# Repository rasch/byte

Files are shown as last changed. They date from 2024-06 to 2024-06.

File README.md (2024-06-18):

# byte

The byte Keyboard, Version 0.1.0

An 8-key, one-handed, business card sized keyboard.

- Keyboard Maintainer: [rasch](https://github.com/rasch/byte)
- Hardware Supported: Byte 0.1.0 (stm32f072)
- Hardware Availability: [byte]

## Getting Board

Check out [the byte releases page][releases] for the required files to get
PCBs manufactured (`plot.zip`) and/or assembled (`bom.csv` and `cpl.csv`). For
those with soldering abilities, an interactive BOM/CPL HTML file (`ibom.html`)
is provided to aid with self-assembly.

During development, it may be preferable (faster) to run rule checks and test
builds locally. There is a `run` shell script in the root of this repository
that is used by the CI/CD for building releases. This script can be run
directly (`./run pcb`), but it requires the `kicad-cli` 8.0+ release to be
installed. Instead, if `podman` is available, it is recommended to use the
`build` script. This script just runs the `./run` script in the
`kicad/kicad:8.0` container. The build files and reports (ERC/DRC) are placed in
the `dist` directory.

The byte Keyboard, Version 0.1.0

In addition to the parts listed in the BOM, the following will be needed for a
complete keyboard:

- 8 x Kailh Low Profile Choc Switches (PG1350)
- 8 x 1u Choc Keycaps (such as MBK)
- USB-C cable to connect to device
- Some rubber feet or neoprene adhesive rubber pads to prevent the board from
  sliding all over the place

## Firmware Installation

Download the firmware, `byte_left.bin` or `byte_right.bin`, from [the byte
releases page][releases]. To flash the keyboard, press the reset button on the
PCB to enter bootloader mode, then run:

```sh
# left-handed artsey
dfu-util -a 0 -d 0483:DF11 -s 0x8000000:leave -D byte_left.bin

# or right-handed artsey
dfu-util -a 0 -d 0483:DF11 -s 0x8000000:leave -D byte_right.bin
```

For details on compiling the firmware, please see the [Github Actions
workflow][build].

## Keymap

The firmware, `byte_left.bin` and `byte_right.bin`, keymaps are based on the
[ARTSEY v0.9.0][artsey] layout. This layout is of limited use for most people,
but it's fun to learn and very useful for those with certain disabilities. The
firmware keymap configuration, `fw/keymaps/left/keymap.c`, provides a good
starting point for making the byte yours! It can be a macropad for your favorite
game, for drawing with Inkscape, for designing keyboards with KiCad, or even
making PowerPoint presentations (Ew!). Check out the [QMK documentation][qmk] to
get inspiration for your own macropad layout!

## License

[Solderpad Hardware License v2.1](LICENSE)

[byte]: https://github.com/rasch/byte
[releases]: https://github.com/rasch/byte/releases/
[image]: https://i.imgur.com/48yj4tK.jpg
[image-back]: https://i.imgur.com/SwSe1no.jpg
[build]: https://github.com/rasch/byte/blob/main/.github/workflows/fw.yml
[artsey]: https://artsey.io/
[qmk]: https://docs.qmk.fm/#/

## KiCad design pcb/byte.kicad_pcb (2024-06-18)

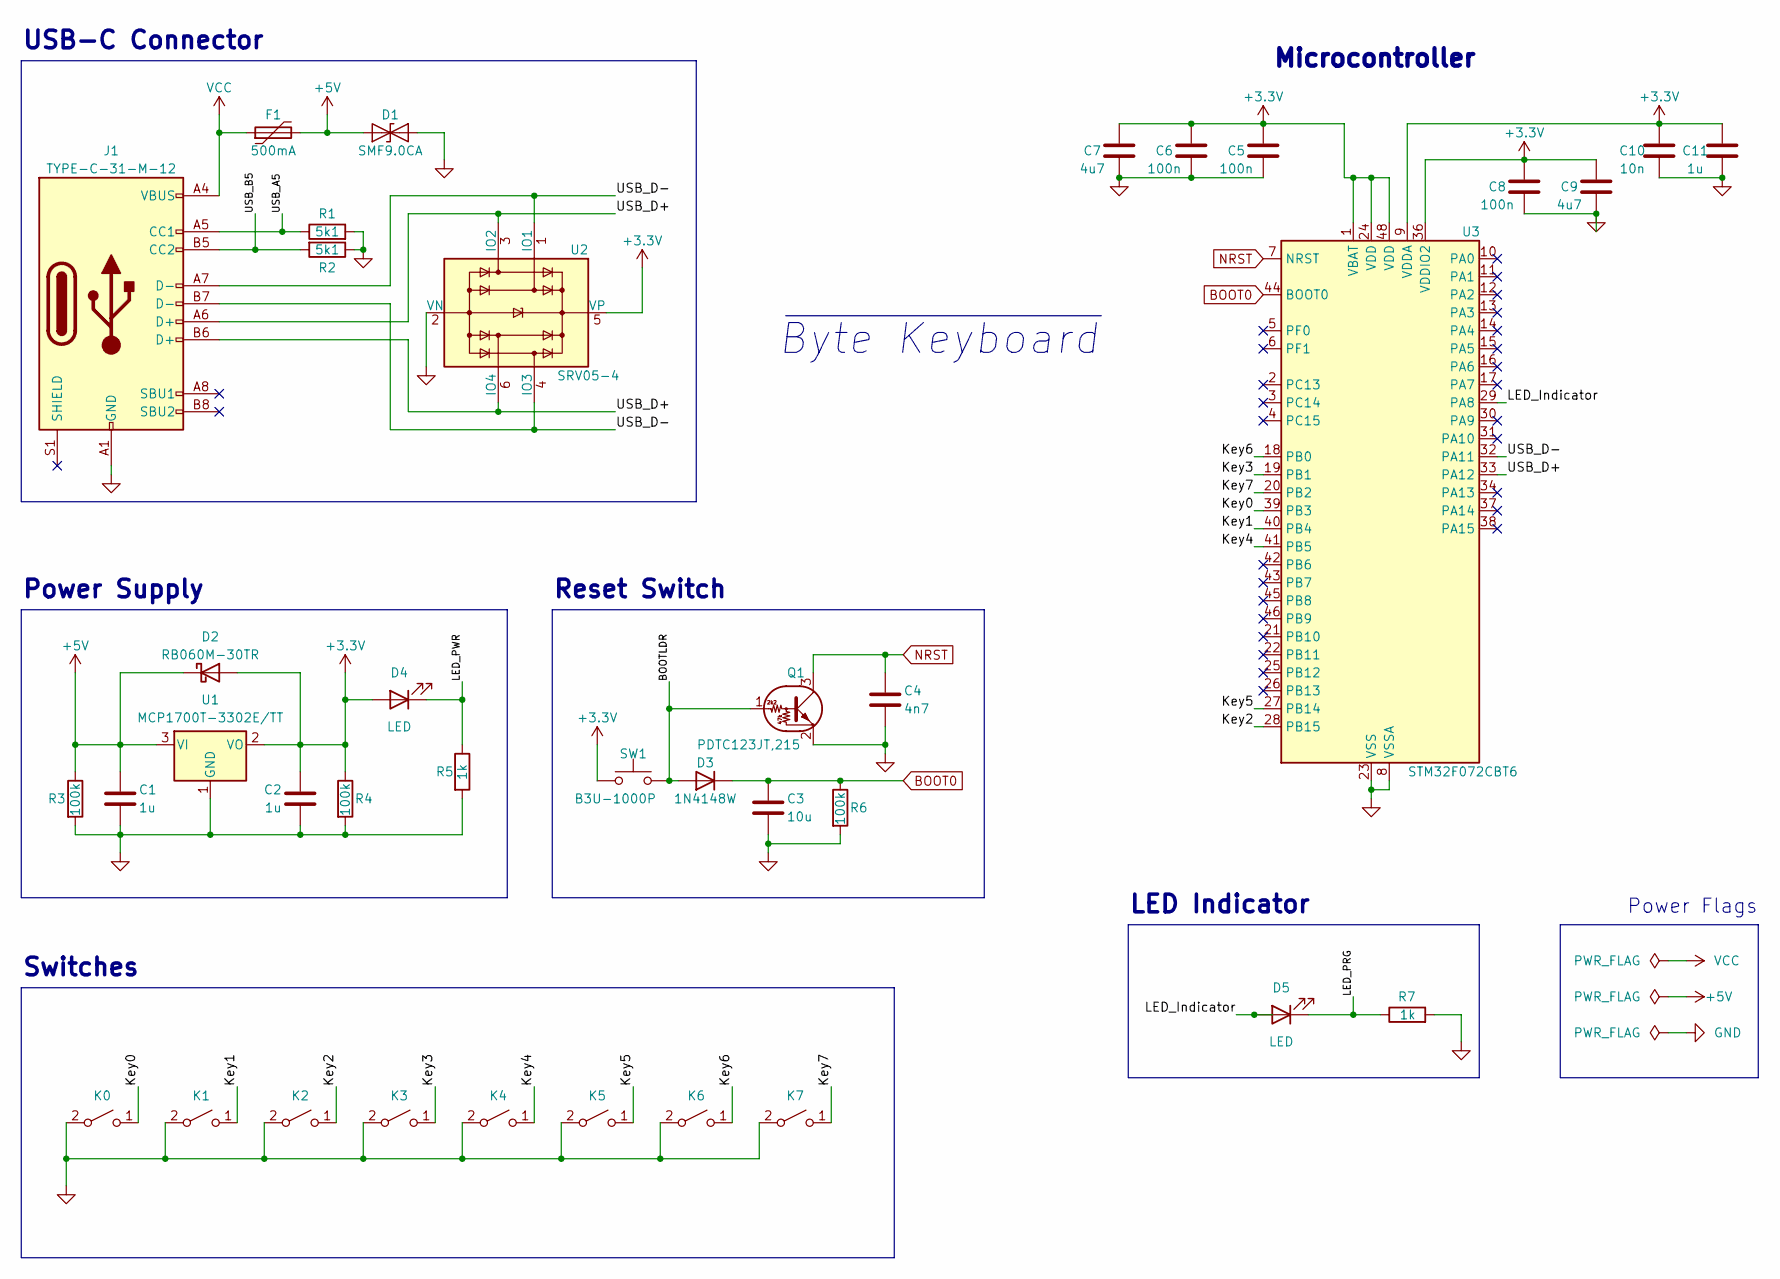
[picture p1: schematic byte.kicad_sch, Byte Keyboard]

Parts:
C1, C2, C11: 1u; C_0805_2012Metric; Part Name Capacitor; LCSC Part C28323
C3: 10u; C_0805_2012Metric; Part Name Capacitor; LCSC Part C17024
C4: 4n7; C_0805_2012Metric; Part Name Capacitor; LCSC Part C717014
C5, C6, C8: 100n; C_0805_2012Metric; Part Name Capacitor; LCSC Part C49678
C7, C9: 4u7; C_0805_2012Metric; Part Name Capacitor; LCSC Part C87998
C10: 10n; C_0805_2012Metric; Part Name Capacitor; LCSC Part C1710
D1: SMF9.0CA; D_SOD-123; Part Name Bidirectional Diode; LCSC Part C435473
D2: RB060M-30TR; D_SOD-123; Part Name Schottky Barrier Diodes; LCSC Part C559324
D3: 1N4148W; D_SOD-123; Part Name Diode; LCSC Part C81598
D4, D5: LED; LED_0603_1608Metric; Part Name Red LED; LCSC Part C84263
F1: 500mA; Fuse_1206_3216Metric; Part Name Polyfuse; LCSC Part C151162
J1: TYPE-C-31-M-12; USB_C_Receptacle_HRO_TYPE-C-31-M-12; Part Name USB C; LCSC Part C165948
K0, K1, K2, K3, K4, K5, K6, K7: SW_KEY; Choc_PG1350_Choc_Spacing
Q1: PDTC123JT,215; SOT-23; Part Name NPN Transistor; LCSC Part C406040
R1, R2: 5k1; R_0805_2012Metric; Part Name Resistor; LCSC Part C27834
R3, R4, R6: 100k; R_0805_2012Metric; Part Name Resistor; LCSC Part C149504
R5, R7: 1k; R_0805_2012Metric; Part Name Resistor; LCSC Part C25318
SW1: B3U-1000P; SW_SPST_B3U-1000P; Part Name Reset Button; LCSC Part C231329
U1: MCP1700T-3302E/TT; SOT-23; Part Name Dropout Regulator; LCSC Part C39051
U2: SRV05-4; SOT-23-6; Part Name TVS Diode Array; LCSC Part C558418
U3: STM32F072CBT6; LQFP-48_7x7mm_P0.5mm; Part Name MCU; LCSC Part C81720

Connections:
+3.3V: C2.1, C5.1, C6.2, C7.1, C8.2, C9.2, C10.2, C11.2, D2.2 (A), D4.2 (A), R4.1, SW1.1, U1.2 (VO), U2.5 (VP), U3.1 (VBAT), U3.9 (VDDA), U3.24 (VDD), U3.36 (VDDIO2), U3.48 (VDD)
+5V: C1.1, D1.1 (A1), D2.1 (K), F1.2, R3.1, U1.3 (VI)
/BOOTLDR: D3.2 (A), Q1.1 (B), SW1.2
/Key0: K0.1 (A), U3.39 (PB3)
/Key1: K1.1 (A), U3.40 (PB4)
/Key2: K2.1 (A), U3.28 (PB15)
/Key3: K3.1 (A), U3.19 (PB1)
/Key4: K4.1 (A), U3.41 (PB5)
/Key5: K5.1 (A), U3.27 (PB14)
/Key6: K6.1 (A), U3.18 (PB0)
/Key7: K7.1 (A), U3.20 (PB2)
/LED_Indicator: D5.2 (A), U3.29 (PA8)
/LED_PRG: D5.1 (K), R7.1
/LED_PWR: D4.1 (K), R5.1
/USB_A5: J1.A5 (CC1), R1.1
/USB_B5: J1.B5 (CC2), R2.2
/USB_D+: J1.A6 (D+), J1.B6 (D+), U2.3 (IO2), U2.6 (IO4), U3.33 (PA12)
/USB_D-: J1.A7 (D-), J1.B7 (D-), U2.1 (IO1), U2.4 (IO3), U3.32 (PA11)
BOOT0: C3.2, D3.1 (K), R6.1, U3.44 (BOOT0)
GND: C1.2, C2.2, C3.1, C4.2, C5.2, C6.1, C7.2, C8.1, C9.1, C10.1, C11.1, D1.2 (A2), J1.A1 (GND), J1.A12 (GND), J1.B1 (GND), J1.B12 (GND), K0.2 (B), K1.2 (B), K2.2 (B), K3.2 (B), K4.2 (B), K5.2 (B), K6.2 (B), K7.2 (B), Q1.2 (E), R1.2, R2.1, R3.2, R4.2, R5.2, R6.2, R7.2, U1.1 (GND), U2.2 (VN), U3.8 (VSSA), U3.23 (VSS), U3.35 (VSS), U3.47 (VSS)
NRST: C4.1, Q1.3 (C), U3.7 (NRST)
VCC: F1.1, J1.A4 (VBUS), J1.A9 (VBUS), J1.B4 (VBUS), J1.B9 (VBUS)

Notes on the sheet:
LED Indicator
Power Flags
Switches
~{${TITLE}}
USB-C Connector
Power Supply
Microcontroller
Reset Switch

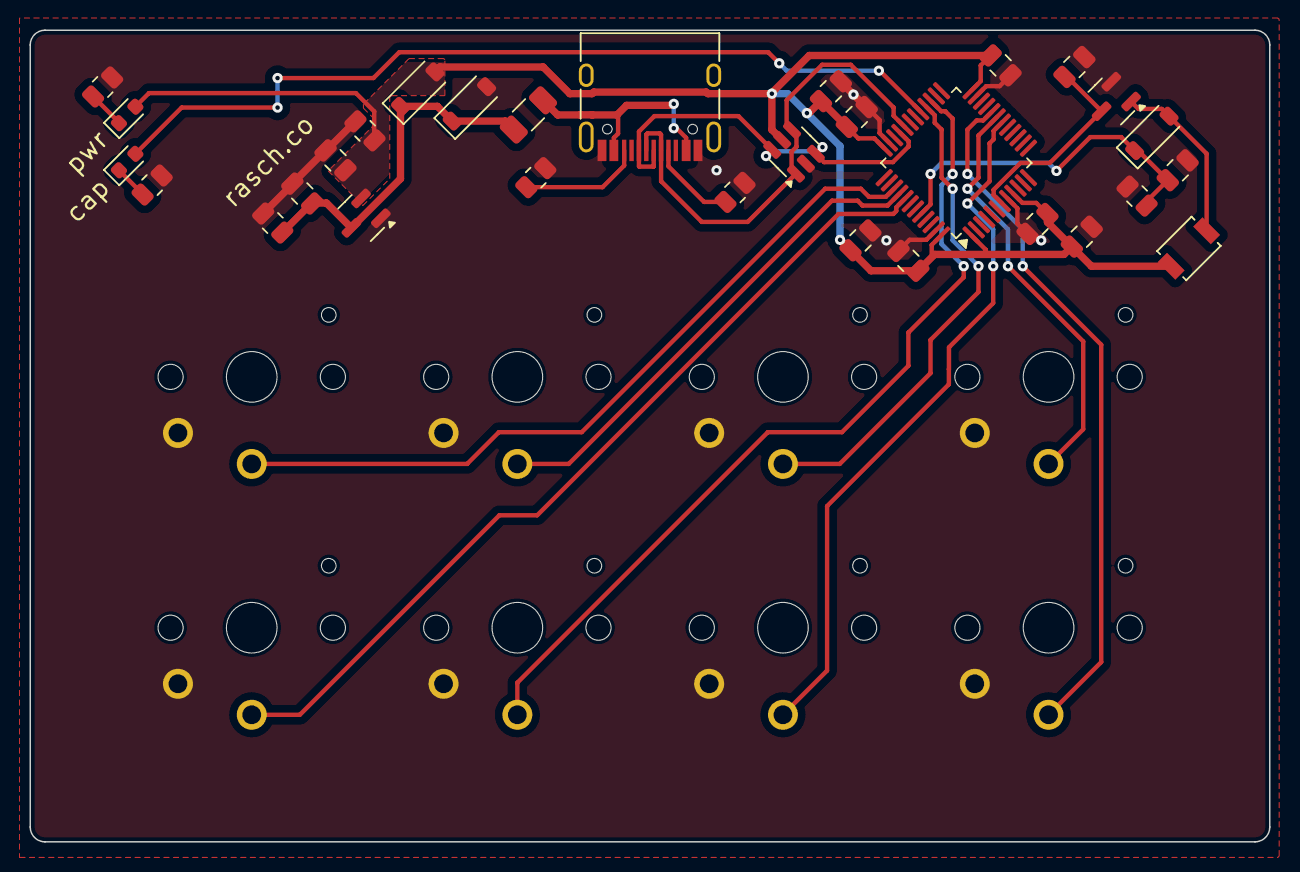
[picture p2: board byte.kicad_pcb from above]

Board: 2 copper layers, 84.0 x 55.0 mm, 38 parts (0 on the bottom side), 22 nets.

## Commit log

2024-06-17 🎉 Initial commit
2024-06-18 🚀 Initial release
    [byte.kicad_pcb, byte.kicad_sch]
2024-06-18 🐛 Fix typo in CI config
